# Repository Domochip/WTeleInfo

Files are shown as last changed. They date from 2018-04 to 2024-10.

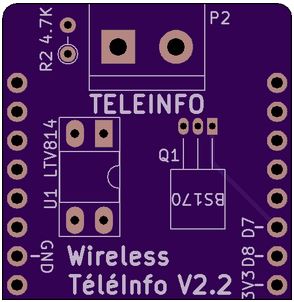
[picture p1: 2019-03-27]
img/pcb.jpg

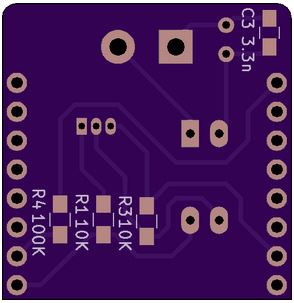
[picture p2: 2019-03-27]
img/pcb2.jpg

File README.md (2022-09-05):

# WTeleInfo
Ce projet utilise un D1 mini et quelques composants pour faire remonter les compteurs EDF à votre domotique.

## Construisez votre WTeleInfo

Tous les fichiers necessaires sont dans le sous-dossier schematic et ont été conçu avec KiCAD.

### Schematic

WTeleInfo schematic 

**Spécial Linky** : <u>Il faut remplacer **R2** par une **1.5K** et **C3** n'est **pas necessaire**</u>

### PCB

WTeleInfo PCBWTeleInfo PCB2

### Imprimez votre boitier

Le projet du boitier (Fusion 360) se trouve dans le dossier `box` 
(Ainsi que les fichiers STL à imprimer directement) 

WTeleInfo Box

### Flash

Le firmware Tasmota-téléinfo est utilisé pour animer le D1Mini  
Vous pouvez le flasher directement depuis la page web "Install tasmota"
https://tasmota.github.io/install/

WTeleInfo Flash

## Démarrage

### Configuration Tasmota

Vous devez appliquer ce Template :  
`{"NAME":"WTeleInfo","GPIO":[0,0,0,0,0,0,0,0,0,5152,0,0,0,0],"FLAG":0,"BASE":18,"CMND":"Module 0|TelePeriod 60"}`

Commande à executer, si vous possedez un compteur Linky en Mode Standard (nouveau protocole):  
`EnergyConfig Standard`

Pour plus de détails, veuillez vous référer à la documentation officielle :  
https://tasmota.github.io/docs/Teleinfo/

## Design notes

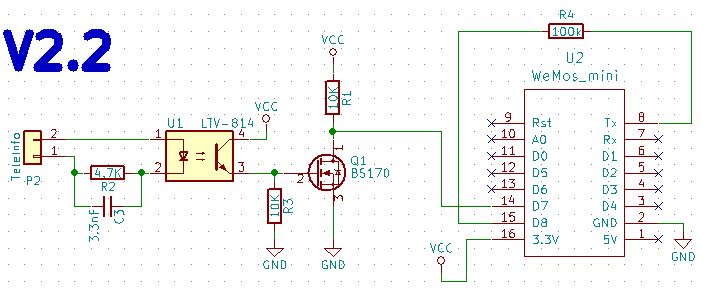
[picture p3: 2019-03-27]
img/schematic.jpg

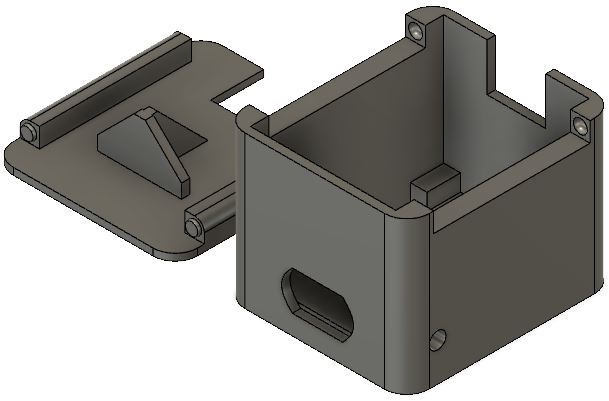
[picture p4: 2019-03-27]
img/box.jpg

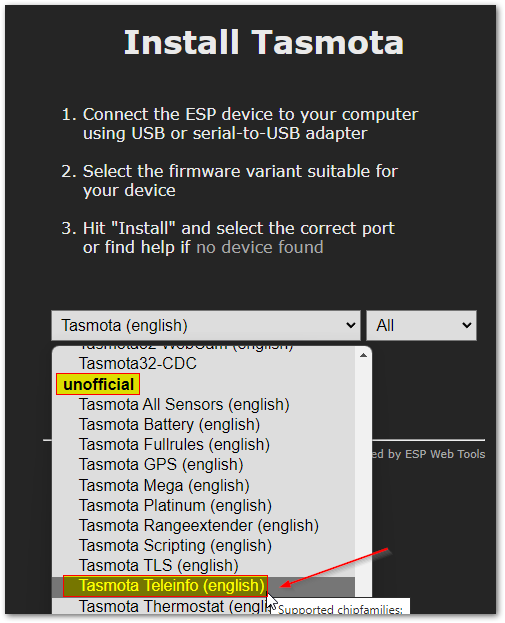
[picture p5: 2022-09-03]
img/flash.png

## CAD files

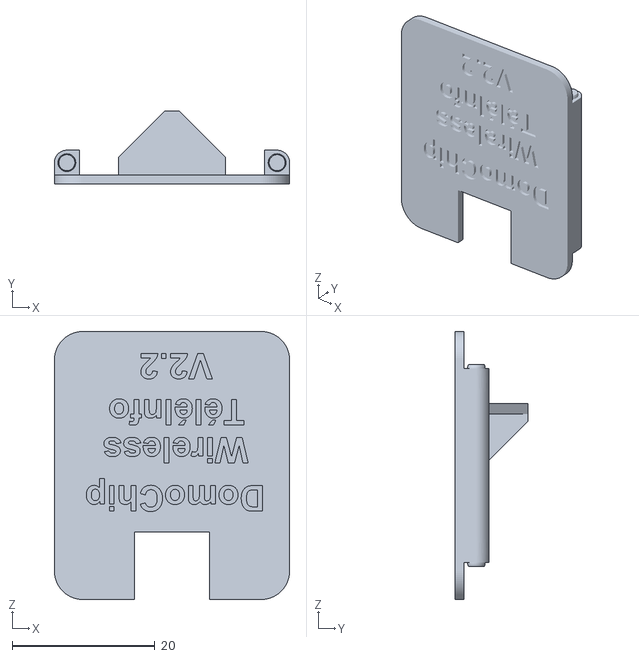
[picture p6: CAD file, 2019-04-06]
box/WirelessTeleInfo Lid v9.stl
33.0 x 10.2 x 37.6

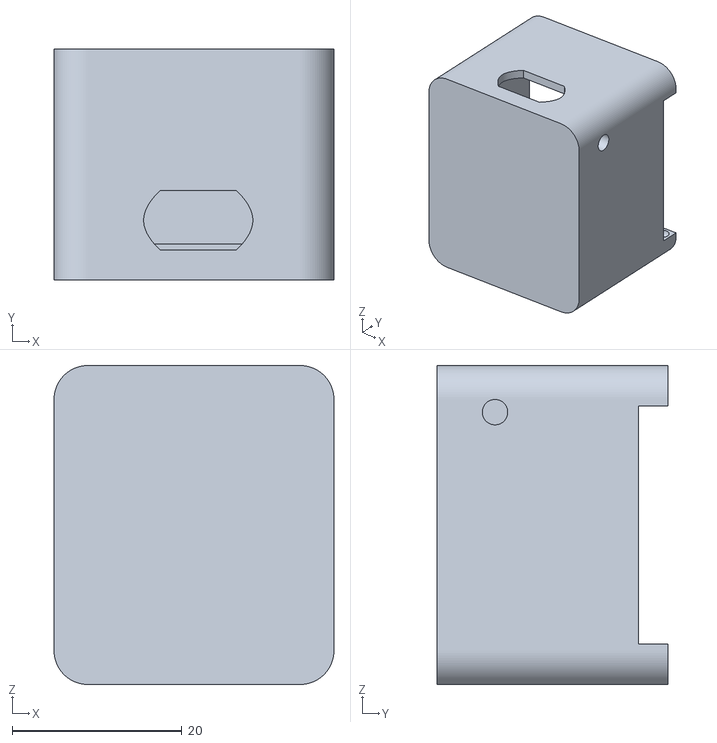
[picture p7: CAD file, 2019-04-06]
box/WirelessTeleInfo Box v9.stl
33.0 x 27.2 x 37.6

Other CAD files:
box/WirelessTéléInfo v9.f3d

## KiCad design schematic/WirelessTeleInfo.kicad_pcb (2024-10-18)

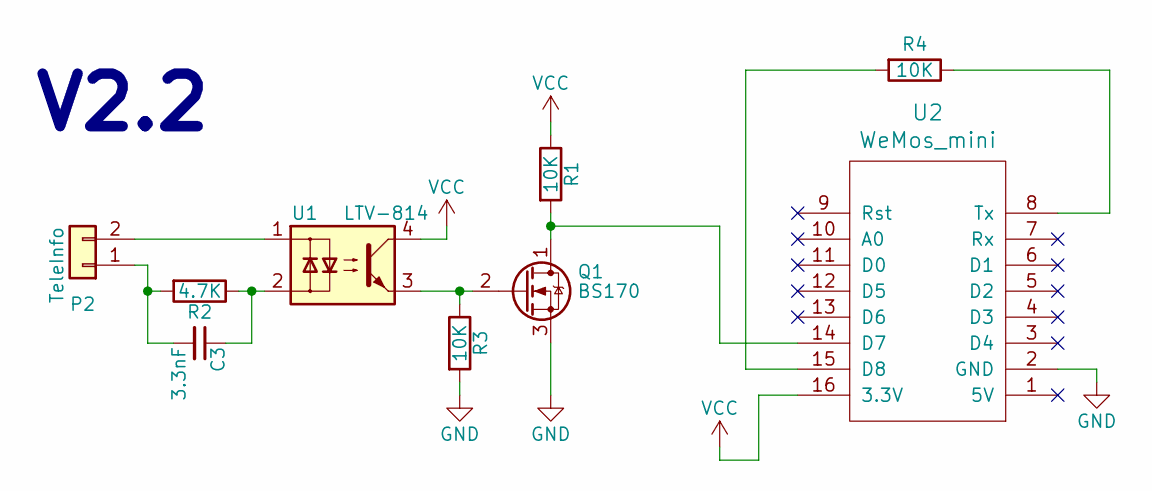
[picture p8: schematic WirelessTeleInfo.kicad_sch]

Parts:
C3: 3.3nF; C_0805_HandSoldering
P2: TeleInfo; TerminalBlock_bornier-2_P5.08mm
Q1: BS170; TO-92_Horizontal2_Inline_Narrow_Oval
R1, R3, R4: 10K; R_0805_HandSoldering
R2: 4.7K; R_Axial_DIN0204_L3.6mm_D1.6mm_P2.54mm_Vertical
U1: LTV-814; DIP-4_W7.62mm_Socket_LongPads
U2: WeMos_mini; wemos-d1-mini-DIL-only

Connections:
GND: Q1.3 (S), R3.2, U2.2 (GND)
unnamed: C3.1, R2.1, U1.2
unnamed: C3.2, P2.1, R2.2
unnamed: P2.2, U1.1
unnamed: Q1.1 (D), R1.2, U2.14 (D7)
unnamed: Q1.2 (G), R3.1, U1.3
unnamed: R4.1, U2.8 (Tx)
unnamed: R4.2, U2.15 (D8)
VCC: R1.1, U1.4, U2.16 (3.3V)

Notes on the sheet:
V2.2

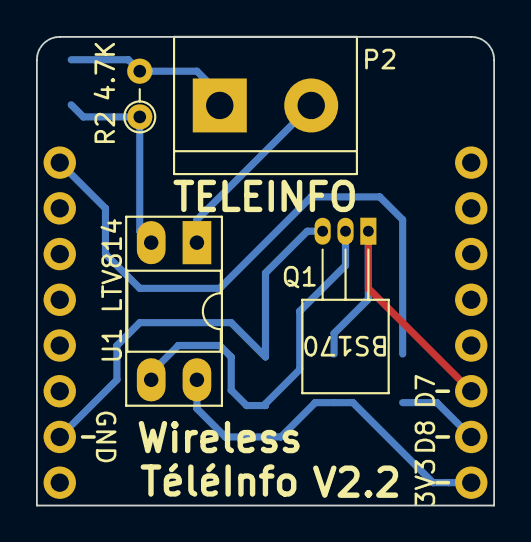
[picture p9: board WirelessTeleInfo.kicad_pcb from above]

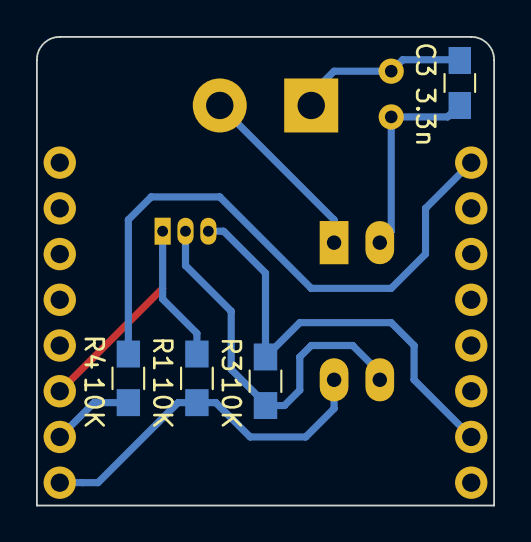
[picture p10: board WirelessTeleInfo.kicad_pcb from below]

Board: 2 copper layers, 25.4 x 26.0 mm, 9 parts (5 on the bottom side), 9 nets.

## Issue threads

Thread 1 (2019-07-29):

arduino.h dependency

azrod, 2019-07-29:
Bonjour,

Pour commencer merci pour ce superbe boulot.

Après avoir tout monté, je test l'installation avec plateformIO mais il semble y avoir un problème.
J'ai essayé avec deux clients différents et à chaque fois la même erreur.
```
Compiling .pio/build/d1_mini/src/LibTeleinfo.cpp.o
Compiling .pio/build/d1_mini/src/WirelessTeleInfo.cpp.o
In file included from src/WirelessTeleInfo.h:8:0,
                 from src/WirelessTeleInfo.cpp:1:
src/Main.h:4:21: fatal error: arduino.h: No such file or directory

*****************************************************************
* Looking for arduino.h dependency? Check our library registry!
*
* CLI  > platformio lib search "header:arduino.h"
* Web  > https://platformio.org/lib/search?query=header:arduino.h
*
*****************************************************************

 #include <arduino.h>
                     ^
compilation terminated.
*** [.pio/build/d1_mini/src/WirelessTeleInfo.cpp.o] Error 1
```
```
Updating tool-scons                      @ 2.20501.7      [Up-to-date]

Platform Manager
================
Platform Espressif 8266
--------
Updating espressif8266                   @ 2.2.2          [Up-to-date]
Updating tool-esptoolpy                  @ 1.20600.0      [Up-to-date]
Updating framework-arduinoespressif8266  @ 2.20502.0      [Up-to-date]
Updating tool-esptool                    @ 1.413.0        [Up-to-date]
Updating toolchain-xtensa                @ 2.40802.190218 [Up-to-date]
```
```
pio --version
PlatformIO, version 4.0.0
```

Merci pour votre aide.
Cordialement

azrod, 2019-08-01:
Bonjour,

J'ai trouvé le problème. Les chemins sont au format "Windows" ..**\**<lefichier.h> donc pas compatible sous Linux.

Par ailleurs dans la documentation il n'est pas indiqué qu'il existe un .bin dans les release.
Du coup j'ai utilisé le soft [esptool](https://github.com/espressif/esptool) pour pouvoir pousser directement le binaire et ça fonctionne.

Closed 2019-08-01.

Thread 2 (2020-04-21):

demande de fonctionnalité

duncan-valleix, 2020-04-21:
je voulais savoir si il était possible de planifier un reboot sois sur l'interface sois via MQTT ?

Davcail, 2020-06-02:
Ce n'est pas prévu mais tout à fait possible. Je vais ajouter une fonction de surveillance de la connexion Wifi pour la réinitialiser si besoin.

Davcail, 2020-06-02:
Le reboot via l'interface Web est présent.

duncan-valleix, 2020-06-03:
> Ce n'est pas prévu mais tout à fait possible. Je vais ajouter une fonction de surveillance de la connexion Wifi pour la réinitialiser si besoin.

se n'est pas pour sa que j'ai demandé si cela était possible, c'est juste que au bout d'une certaine durée de lecture des info des caractères se retrouve mise sur les ligne je joindrai des Screenshots, et la seul manière de résoudre sa a était pour moi de reboot le wemos

duncan-valleix, 2020-06-03:
et je pensais faire une scénario, ou si il y a plus de caractère que prévu (ou même si c'est des lettre a la place des chiffre) sur tel ou tel ligne envoie une demande de reboot via mqtt

Domochip, 2021-02-07:
Malhereusement, ce bug semble provenir de la librairie Teleinfo que j'utilise.
Je la met à jour et on verra si c'est corrigé.

Closed 2021-02-07.

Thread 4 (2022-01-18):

PCB Wireless Teleinfo et mode standard linky

StepG38, 2022-01-18:
Bonjour,
Bravo pour ce projet qui m'intéresse fortement car j'ai 3 compteurs à monitorer.
Pouvez vous m'indiquer ou trouver le PCB pour ce projet ?
Merci par avance
Stéphane

Domochip, 2022-01-23:
Bonjour,
Désolé, je n'en ai pas en stock.
Si vous cherchez le PCB nu, je vous conseille de passer par OSHPark.
Bonne Journée

StepG38, 2022-01-23:
Bonjour,
Merci pour le retour.
Stéphane

StepG38, 2022-01-25:
Bonjour,
Je viens d'essayer avec mon linky en mode standard et rien ne remonte.
C'est normal ?
Merci par avance
Stéphane

Domochip, 2022-01-25:
Dimanche, je regardais justement la librairie teleinfo que j'utilise et j'ai vu qu'elle semble gérer le linky en mode standard.
Je vais regarder rapidement si je peux ajouter cette option.

StepG38, 2022-01-25:
Super merci beaucoup !!

StepG38, 2022-01-25:
Pas de souci pour faire des tests !!

Domochip, 2022-01-26:
Les premiers test ne sont pas concluant.
J'ai repassé un cable depuis mon compteur pour débugger.

StepG38, 2022-01-26:
Merci pour ton travail !!

Domochip, 2022-01-26:
C'est corrigé.
Mon linky est en mode historique.
Pourrais-tu essayer avec la pre-release que je viens de publier?
Il me faudrait ensuite le contenu de la page suivante :
`http://{IP}/getAllLabel`

Il me semble que le numéro de série du compteur est ADSC. Je voudrais en être sûr.
N'oublie pas de modifier quelques caractères afin de ne pas publier ton numéro de série justement.
Merci

StepG38, 2022-01-26:
OK je test

StepG38, 2022-01-26:
J'ai ca avec des conexion et deconexion
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

StepG38, 2022-01-26:
{"ADSC":"02q876531XXX"
," NTARF":"O  NJOURF"
," SINSTS1":"C  SINSTS2"
," EASD04":"I  IRMS1"
}

StepG38, 2022-01-26:
En mettant historique il reste connecté
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

StepG38, 2022-01-26:
La valeur change :
021876531AAA
02q876531AAA
021x76531AAA

StepG38, 2022-01-26:
Au fait je suis en tri

Domochip, 2022-01-26:
Il faudrait connecter le D1Mini au PC par le micro USB est ouvrir le port série à 9600bps.
Au démarrage, il y a une sortie indiquant la connection au réseau Wifi, etc..
Ca m'interesse de savoir au bout de combien de temps ca explose.
Quelle est l'Upload Period (60secondes?)

StepG38, 2022-01-26:
J'ai mis 5 s
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

StepG38, 2022-01-26:
Comment tu ouvre le port usb ?

Domochip, 2022-01-26:
Avec putty par exemple.
5sec! ça me parait très court. Pourquoi pas 60sec?

StepG38, 2022-01-27:
J'avait essayé avec putty mais la console reste noir
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

Avec mes 3 autres compteurs Sagem j'ai mis 5 secondes pour voir rapidement la mise en route des appareil branché dessus.
je peux remettre à 60 s pour le linky si il faut

StepG38, 2022-01-27:
Hello,
Tu as pu avancer ?

Domochip, 2022-01-28:
Il faut que je scripte un faux compteur. Comme ca je pourrai débugger correctement.

StepG38, 2022-01-28:
Ok
Merci pour ton aide 😉

Domochip, 2022-01-29:
J'ai fait les tests.
J'observe un soucis avec la publication MQTT pour un Linky en mode Standard.
Mais si la partie Home Automation est désactivé :
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

La page `http://{IP}/getAllLabel` me retourne bien les infos :
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

StepG38, 2022-01-29:
Salut,
Du coup je ne peux pas passer par MQTT ?
Comment récupérer les infos alors ?

Domochip, 2022-01-29:
Je regarde pour corriger le problème.
Mais ca m'interesserait de savoir si tu as la même chose?

StepG38, 2022-01-29:
OK je test

StepG38, 2022-01-29:
c'est un peu long car je dois remettre le programme dans l'ESP

StepG38, 2022-01-29:
J'ai rien
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

Domochip, 2022-01-29:
Il faut vérifier le cablage avec le compteur

StepG38, 2022-01-29:
ca marche avec mon rpi jeedom et le plugin teleinfo

StepG38, 2022-01-29:
Oups j'ai pas mis l'ESP dans la boite

StepG38, 2022-01-29:
J'ai ca

{"ADSC":"02q876531XXX"
," NTARF":"O  NJOURF"
," PRM":"%  RGLAIS"
}

StepG38, 2022-01-29:
On parle bien de ta dernière version Build version : 1.4.1/3.4.0 ?

Domochip, 2022-01-29:
J'ai identifié le problème de publish MQTT.
Je viens de faire une nouvelle compil et je l'ai mise dans la pre-release :
WirelessTeleInfo.v1.4.1-3.4.0**V2**.bin

StepG38, 2022-01-29:
OK

StepG38, 2022-01-29:
Du cout il faut tester avec MQTT ?

Domochip, 2022-01-29:
oui

StepG38, 2022-01-29:
OK je suis obligé de téléverser un firmware blank a chaque fois donc c'est un peu long

Domochip, 2022-01-29:
ah bon?

StepG38, 2022-01-29:
sinon j'ai du mal a me connecter en wifi en direct sur l'ESP

StepG38, 2022-01-29:
J'ai pas essayer la mise à jour du firmware à partir de ta page web

Domochip, 2022-01-29:
J'ai corrigé le défaut d'affichage sur la page Web => V3

StepG38, 2022-01-29:
Toujours pas
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

StepG38, 2022-01-29:
J'ai fait avec
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

Domochip, 2022-01-29:
Le coup du '1' qui est remplacé par un 'q' est très étonnant.
surtout que le topic est construit à partir d'ADSC donc '02**q**876531' == '02187653**q**'

StepG38, 2022-01-29:
Pareil

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

Domochip, 2022-01-29:
les infos provenant du compteur sont vérifiés grâce au Checksum.
Donc si on les a, c'est qu'elles ont été validé par la librairie Teleinfo.
Si en utilisant le flash par la page Web ca ne fonctionne toujours pas, Il faut tester avec un autre module

StepG38, 2022-01-29:
C'est pas tout le temps
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

StepG38, 2022-01-29:
C'est pas tout le temps
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

StepG38, 2022-01-29:
ca revient

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

Domochip, 2022-01-29:
Faut voir avec un autre module d1 mini, ou vérifier que son alim est correcte aussi

StepG38, 2022-01-29:
Je vais être obligé de te laisser
merci pour ton aide
A demain si tu es dispo
Bonne soirée
Stéphane

StepG38, 2022-01-29:
Je vais essayer

StepG38, 2022-01-29:
idem
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

StepG38, 2022-01-29:
Je te laisse
Bonne soirée !

StepG38, 2022-01-30:
Hello,
Le montage que j'utilise fonctionne bien avec mes 3 autres compteurs sagem.
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

Domochip, 2022-01-30:
Quel en est le schéma?

StepG38, 2022-01-30:
C'est un wifinfo réalisé par rolrider

[](https://www.jeedom.com/forum/viewtopic.php?t=21758)

StepG38, 2022-01-31:
Ci-dessous le schémas

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

Domochip, 2022-01-31:
Coté schéma, tout à l'air bon.De toute manière
Je viens de contacter Enedis, et en 2 minutes, ils ont passé mon compteur en mode Standard.

De mon coté, tout fonctionne bien :
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

Pas de lettre q (j'ai bien un 1 dans mon ADSC).
l'url getAllLabel fonctionne aussi correctement :
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

StepG38, 2022-01-31:
Réactif Enedis !!
De mon coté je rebrancher mon RPI avec Jeedom et téléinfo avec un modem USB carte electronique et tout fonctionne bien.
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

Domochip, 2022-01-31:
un défaut d'affichage ? :
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

StepG38, 2022-01-31:
Je comprends pas !

StepG38, 2022-01-31:
Je vais refaire une config propre jeedom juste avec le teleinfo

StepG38, 2022-01-31:
Sinon en mode historique cela fonctionne ?

Domochip, 2022-01-31:
Oui, En Historique, ça fonctionne aussi.

StepG38, 2022-01-31:
Du coup je ne sais plus quoi faire !

Domochip, 2022-01-31:
avec le RPi et Jeedom, en recréant l'équipement, y a-t-il toujours des étiquettes incorrectes?

StepG38, 2022-01-31:
J'ai ca !
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

StepG38, 2022-01-31:
Pour l'intensité instantanée je pense qu'il faut prendre :
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

Domochip, 2022-01-31:
J'utilise le dernier doc d'Enedis : Enedis-NOI-CPT_54E.pdf
As-tu un besoin particulier d'avoir l'intensité?

En passant le plugin en débug, ca sort du log interessant je pense

StepG38, 2022-01-31:
[log teleinfo.zip](https://github.com/Domochip/WirelessTeleInfo/files/7974439/log.teleinfo.zip)

Domochip, 2022-01-31:
tout à l'air OK
Attention, il te faut supprimer ce log car il contient des infos sensibles!

Domochip, 2022-02-01:
Je te conseille de faire un test avec tasmota :
https://tasmota.github.io/docs/Teleinfo/

StepG38, 2022-02-01:
Bonjour à tous,
Petit retour sur mon problème de swap qui n'est plus.
Je suis simplement passé sur un RPI 4 2Go (et oui impossible de trouver des 4Go) et le swap est à 0

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

Stéphane

Domochip, 2022-02-01:
?

StepG38, 2022-02-01:
Je vais tester avec Tasmota dans l'après midi

StepG38, 2022-02-01:
Hello,
Test avec Tasmota

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

Aprés j'ai fait dans les commandes : EnergyConfig standard

`00:00:00.001 HDW: ESP8266EX
00:00:00.050 CFG: Loaded from flash at F5, Count 31
00:00:00.055 QPC: Count 1
00:00:00.064 Project tasmota - Tasmota Version 2022.01.3(teleinfo)-2_7_4_9(2022-02-01T14:35:17)
00:00:00.064 TIC: RX on GPIO13, baudrate 9600
00:00:00.106 SNS: Hardware Serial
00:00:00.106 TIC: using hardware serial
00:00:00.521 WIF: Connecting to AP1 SG Channel 6 BSSId 60:35:C0:C4:2A:96 in mode 11n as tasmota-9F52DB-4827...
00:00:03.501 WIF: Connected
00:00:03.752 HTP: Web server active on tasmota-9F52DB-4827 with IP address 192.168.1.16
16:40:19.298 MQT: Attempting connection...
16:40:19.317 MQT: Connected
16:40:19.319 MQT: tele/tasmota_9F52DB/LWT = Online (retained)
16:40:19.321 MQT: cmnd/tasmota_9F52DB/POWER =
16:40:19.331 MQT: tele/tasmota_9F52DB/INFO1 = {"Info1":{"Module":"Generic","Version":"2022.01.3(teleinfo)","FallbackTopic":"cmnd/DVES_9F52DB_fb/","GroupTopic":"cmnd/tasmotas/"}}
16:40:19.335 MQT: tele/tasmota_9F52DB/INFO2 = {"Info2":{"WebServerMode":"Admin","Hostname":"tasmota-9F52DB-4827","IPAddress":"192.168.1.16"}}
16:40:19.338 MQT: tele/tasmota_9F52DB/INFO3 = {"Info3":{"RestartReason":"Software/System restart"}}
16:40:21.455 QPC: Reset
16:40:24.417 MQT: tele/tasmota_9F52DB/STATE = {"Time":"2022-02-01T16:40:24","Uptime":"0T00:00:11","UptimeSec":11,"Vcc":2.832,"Heap":26,"SleepMode":"Dynamic","Sleep":50,"LoadAvg":19,"MqttCount":1,"Wifi":{"AP":1,"SSId":"SG","BSSId":"60:35:C0:C4:2A:96","Channel":6,"Mode":"11n","RSSI":100,"Signal":-27,"LinkCount":1,"Downtime":"0T00:00:05"}}
16:40:24.427 MQT: tele/tasmota_9F52DB/SENSOR = {"Time":"2022-02-01T16:40:24","ENERGY":{"TotalStartTime":"2022-02-01T16:07:50","Total":0.000,"Yesterday":0.000,"Today":0.000,"Period": 0,"Power": 0,"Current":0.000},"TIC":{}}
16:41:48.269 CMD: EnergyConfig
16:41:48.273 TIC: Settings Mode:standard, RX:GPIO13, EN:None, Raw:noraw, Skip:0, Limit:0
16:41:48.277 MQT: stat/tasmota_9F52DB/RESULT = {"EnergyConfig":"Done"}`

Mais toujours rien !!

Dans MQTT

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

StepG38, 2022-02-01:
Je viens de tester avec le firmware de Teleinfo 9.1.1 by Nicolas Bernaerts

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

J'ai 230 v !! Super !!

StepG38, 2022-02-02:
EUREKA !!!!
J'ai fait un proto suivant le schéma V2.2 et utilisé la dernière release WirelessTeleInfo.v1.4.1-3.4.1 et tout semble fonctionner !!
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

GRAND MERCI pour ta patience et ton aide.
Stéphane

Domochip, 2022-02-02:
cool!!!!
ça, c'est la persévérence. :-D

StepG38, 2022-02-02:
Effectivement j'ai pas lâché sur ce coup la mais beaucoup de temps passé !
Encore merci pour ton aide et bravo pour le travail que tu as fait sur ce projet.
A bientôt
Stéphane

Closed 2022-03-04.

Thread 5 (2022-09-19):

Home Assistant auto discovery

azrod, 2022-09-19:
Bonjour,

Pourriez-vous ajouter une option pour publier dans MQTT l'auto configuration des entités HomeAssistant ?

En effet en publiant dans le topic de home assistant par exemple : **homeassistant/sensor/teleinfo/hchc/config** il est possible de configurer une entités de type sensor de façon automatique.

Voici le configuration JSON "Type" pour un sensor a publier
```
{
    "availability": [
        {
            "topic": "teleinfo/connected",
            "payload_available": "1",
            "payload_not_available": "0"
        }
    ],
    "device": {
        "identifiers": [
            "<SerialNumber>"
        ],
        "manufacturer": "DOMOCHIP",
        "model": "WTELEINFO",
        "name": "WTELEINFO",
        "sw_version": "<WTELEINFO_VERSION>"
    },
    "enabled_by_default": true,
    "json_attributes_topic": "teleinfo/HCHC",
    "name": "Heures Creuses",
    "device_class": "energy",
    "state_class": "total_increasing",
    "state_topic": "teleinfo/HCHC",
    "unique_id": "wteleinfo_<SerialNumber>_hchc",
    "unit_of_measurement": "Wh",
    "force_update": true
}
```

L'avantage de cette déclaration c'est qu'on déclare un "appareil" dans home assistant dans lequel on retrouvera tous les sensors associés.
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

Voici le JSON que j'ai utilisé pour l'exemple
```
{
    "availability": [
        {
            "topic": "teleinfo/connected",
            "payload_available": "1",
            "payload_not_available": "0"
        }
    ],
    "device": {
        "identifiers": [
            "00e609eb"
        ],
        "manufacturer": "DOMOCHIP",
        "model": "WTELEINFO",
        "name": "WTELEINFO",
        "sw_version": "1.4.1/3.4.1"
    },
    "enabled_by_default": true,
    "json_attributes_topic": "teleinfo/HCHC",
    "name": "Heures Creuses",
    "device_class": "energy",
    "state_class": "total_increasing",
    "state_topic": "teleinfo/HCHC",
    "unique_id": "wteleinfo_00e609eb_hchc",
    "unit_of_measurement": "Wh",
    "force_update": true
}

```

Si nécessaire voici la documentation pour l'auto configuration d'une entités de type sensor dans HomeAssistant : [https://www.home-assistant.io/integrations/sensor.mqtt/](https://www.home-assistant.io/integrations/sensor.mqtt/) et la documentation plus générale sur le Discovery MQTT [https://www.home-assistant.io/docs/mqtt/discovery/](https://www.home-assistant.io/docs/mqtt/discovery/)

Merci

Domochip, 2022-10-02:
Bonjour,

Ce projet viens de passer à Tasmota. l'intégration home assistant est disponible sur tasmota

Closed 2023-07-08.

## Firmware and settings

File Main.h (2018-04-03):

#ifndef Main_h
#define Main_h

#include <arduino.h>

#include "data\status.html.gz.h"
#include "data\config.html.gz.h"
#include "data\fw.html.gz.h"
#include "data\discover.html.gz.h"

//DomoChip Informations
//------------Compile for 1M 64K SPIFFS------------
//Configuration Web Pages :
//http://IP/
//http://IP/config
//http://IP/fw
//TeleInfo Request Web Pages
//http://IP/getAllLabel
//http://IP/getLabel?name=HCHC

//include Application header file
#include "WirelessTeleInfo.h"

#define APPLICATION1_NAME "WTeleInfo"
#define APPLICATION1_DESC "DomoChip Wireless TeleInfo"
#define APPLICATION1_CLASS WebTeleInfo

#define VERSION_NUMBER "3.1.2"

#define DEFAULT_AP_SSID "WirelessTeleInfo"
#define DEFAULT_AP_PSK "PasswordTeleInfo"

//Enable developper mode (SPIFFS editor)
#define DEVELOPPER_MODE 0

//Pin RX used to receive TéléInformation signal @ 1200bauds
#define SERIAL_SPEED 1200

//FOR ESP-01 : there is only one serial and RX pin should be up at start, so TeleInfo signal should be controlled by a pin
//(I cabled GPIO0 instead of GND to the Mosfet with a pull-up resistor, that way, TeleInfo signal comes only if GPIO0 go to GND)
#define TELEINFO_CONTROL_PIN 0

//Choose Pin used to boot in Rescue Mode
#define RESCUE_BTN_PIN 2

//construct Version text
#if DEVELOPPER_MODE
#define VERSION VERSION_NUMBER "-DEV"
#else
#define VERSION VERSION_NUMBER
#endif

#endif

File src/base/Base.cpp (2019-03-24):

#include "Base.h"

bool Application::SaveConfig()
{
  File configFile = SPIFFS.open(String('/') + _appName + F(".json"), "w");
  if (!configFile)
  {
    Serial.println(F("Failed to open config file for writing"));
    return false;
  }

  configFile.print(GenerateConfigJSON(true));
  configFile.close();
  return true;
}

bool Application::LoadConfig()
{
  //special exception for Core, there is no Core.json file to Load
  if (_appId == '0')
    return true;

  bool result = false;
  File configFile = SPIFFS.open(String('/') + _appName + F(".json"), "r");
  if (configFile)
  {

    int memoryAllocation = JSON_DOC_MEM_STEP;

    while (memoryAllocation <= JSON_DOC_MAX_MEM_SIZE)
    {
      DynamicJsonDocument jsonDoc(memoryAllocation);

      configFile.seek(0);

      auto deserializeJsonError = deserializeJson(jsonDoc, configFile);
      //if parsing OK, pass it to application then stop loop
      if (deserializeJsonError.code() == DeserializationError::Ok)
      {
        ParseConfigJSON(jsonDoc);
        result = true;
        break;
      }
      //if parsing result is not a NoMemory, there is a problem in JSON
      if (deserializeJsonError.code() != DeserializationError::NoMemory)
      {
        Serial.print(F("deserializeJson() failed : "));
        Serial.println(deserializeJsonError.c_str());
        break;
      }

      //there, we need to increase memorySize and loop
      memoryAllocation += JSON_DOC_MEM_STEP;
    }

    configFile.close();
  }

  //if loading failed, then run a Save to write a good one
  if (!result)
    SaveConfig();

  return result;
}

void Application::Init(bool skipExistingConfig)
{
  bool result = true;

  Serial.print(F("Start "));
  Serial.print(_appName);
  Serial.print(F(" : "));

  SetConfigDefaultValues();

  if (!skipExistingConfig)
    result = LoadConfig();

  //Execute specific Application Init Code
  result = AppInit() && result;

  if (result)
    Serial.println(F("OK"));
  else
    Serial.println(F("FAILED"));
}

void Application::InitWebServer(AsyncWebServer &server, bool &shouldReboot, bool &pauseApplication)
{
  char url[16];

  //HTML Status handler
  sprintf_P(url, PSTR("/status%c.html"), _appId);
  server.on(url, HTTP_GET, [this](AsyncWebServerRequest *request) {
    AsyncWebServerResponse *response = request->beginResponse_P(200, F("text/html"), GetHTMLContent(status), GetHTMLContentSize(status));
    response->addHeader("Content-Encoding", "gzip");
    request->send(response);
  });

  //HTML Config handler
  sprintf_P(url, PSTR("/config%c.html"), _appId);
  server.on(url, HTTP_GET, [this](AsyncWebServerRequest *request) {
    AsyncWebServerResponse *response = request->beginResponse_P(200, F("text/html"), GetHTMLContent(config), GetHTMLContentSize(config));
    response->addHeader("Content-Encoding", "gzip");
    request->send(response);
  });

  //HTML fw handler
  sprintf_P(url, PSTR("/fw%c.html"), _appId);
  server.on(url, HTTP_GET, [this](AsyncWebServerRequest *request) {
    AsyncWebServerResponse *response = request->beginResponse_P(200, F("text/html"), GetHTMLContent(fw), GetHTMLContentSize(fw));
    response->addHeader("Content-Encoding", "gzip");
    request->send(response);
  });

  //HTML discover handler
  sprintf_P(url, PSTR("/discover%c.html"), _appId);
  server.on(url, HTTP_GET, [this](AsyncWebServerRequest *request) {
    AsyncWebServerResponse *response = request->beginResponse_P(200, F("text/html"), GetHTMLContent(discover), GetHTMLContentSize(discover));
    response->addHeader("Content-Encoding", "gzip");
    request->send(response);
  });

  //JSON Status handler
  sprintf_P(url, PSTR("/gs%c"), _appId);
  server.on(url, HTTP_GET, [this](AsyncWebServerRequest *request) {
    AsyncWebServerResponse *response = request->beginResponse(200, F("text/json"), GenerateStatusJSON());
    response->addHeader("Cache-Control", "no-cache");
    request->send(response);
  });

  //JSON Config handler
  sprintf_P(url, PSTR("/gc%c"), _appId);
  server.on(url, HTTP_GET, [this](AsyncWebServerRequest *request) {
    AsyncWebServerResponse *response = request->beginResponse(200, F("text/json"), GenerateConfigJSON());
    response->addHeader("Cache-Control", "no-cache");
    request->send(response);
  });

  sprintf_P(url, PSTR("/sc%c"), _appId);
  server.on(url, HTTP_POST, [this](AsyncWebServerRequest *request) {
    if (!ParseConfigWebRequest(request))
      return;

    //then save
    bool result = SaveConfig();

    //Send client answer
    if (result)
    {
      request->send(200);
      _reInit = true;
    }
    else
      request->send(500, F("text/html"), F("Configuration hasn't been saved"));
  });

  //Execute Specific Application Web Server initialization
  AppInitWebServer(server, shouldReboot, pauseApplication);
}

void Application::Run()
{
  if (_reInit)
  {
    Serial.print(F("ReStart "));
    Serial.print(_appName);
    Serial.print(F(" : "));

    if (AppInit(true))
      Serial.println(F("OK"));
    else
      Serial.println(F("FAILED"));

    _reInit = false;
  }

  AppRun();
}

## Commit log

2018-03-13 V3.1.1 Initial Commit
    [WirelessTeleInfo v1.1.scad, WirelessTeleInfo.kicad_pcb, WirelessTeleInfo.sch]
2018-06-20 Switch to Base V1.0.10
2018-10-26 V1.1.5/3.2.0 Switch to Base V1.1.5
2018-11-17 Switch to Base V1.1.6
    - No More PowerShell
    - GZIP and convertion to header done in python with platformIO
    - Webpages small improvement
2019-03-17 V3.2.3 Switch to D1 Mini !!! Upgrade to Base V1.1.7
2019-03-17 Switch schematic to D1 Mini
2019-03-17 Change box for D1 Mini (Use Fusion 360)
    [WirelessTeleInfo v1.1.scad, WirelessTéléInfo v8.f3d]
2019-03-27 Update Schematic for better stability
    [WirelessTeleInfo.kicad_pcb, WirelessTeleInfo.sch]
2019-03-27 V3.2.5 use RX2 pin to receive Teleinfo ESPSoftwareSerial removed Add lib dependencies
2019-03-27 Update Box
    [WirelessTéléInfo v8.f3d, WirelessTéléInfo v9.f3d]
2019-04-05 Fix Schematic
    [WirelessTeleInfo.kicad_pcb, WirelessTeleInfo.sch]
2019-04-06 Add Box in stl format
    [WirelessTeleInfo Box v9.stl, WirelessTeleInfo Lid v9.stl]
2019-04-10 V3.3.1 BugFix MQTT reconnection
    [Main.h]
2020-10-16 Update WirelessTeleInfo.cpp
    with latest version of jeedom, completeURI should be now : "http$tls$://$host$/plugins/teleinfo/core/php/jeeTeleinfo.php?apikey=$apikey$&ADCO=$adco$"
2024-10-18 Cleanup and update schematic to KiCAD 8
    [WirelessTeleInfo.kicad_pcb, WirelessTeleInfo.kicad_sch, WirelessTeleInfo.sch]
2024-10-18 Add gitignore for KiCad
